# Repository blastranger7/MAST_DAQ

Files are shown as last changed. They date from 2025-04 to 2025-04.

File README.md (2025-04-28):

# MAST_DAQ

## A data aquisition system for the McMaster Aerospace Team
Intended to gather altitude, accelleration, and GPS data and save it to a SD card as a csv file.

### Hardware
> ESP32

> GT-U7  GPS Module

> MPU6050 Accelerometer

> Micro SD Card adapter

### Use
Turning the system on will immediately create a new csv file on the SD card and start writing accelerometer and GPS data to it.

If the system in turned on and GPS data is all 0s then the likely cause is bad sattelite reception and you need to move outside.

### Notes

.cddx file is used to design the circuit diagram at https://www.circuit-diagram.org/editor/

The SD Card in this system needs to be formatted to FAT32. Most SD cards do not come this way and it is likely third party software is needed if the SD card is over 32GB. Free software can be found to do this, although I've found that **DiskGenius** (https://www.diskgenius.com) works the best (also free).

Use an ESP32 and not an Arduino as an Arduino doesn't have enough SRAM to handle the 3 communication protocols needed.

Hold down the boot button on the ESP32 for a second or two while connecing when uploading code

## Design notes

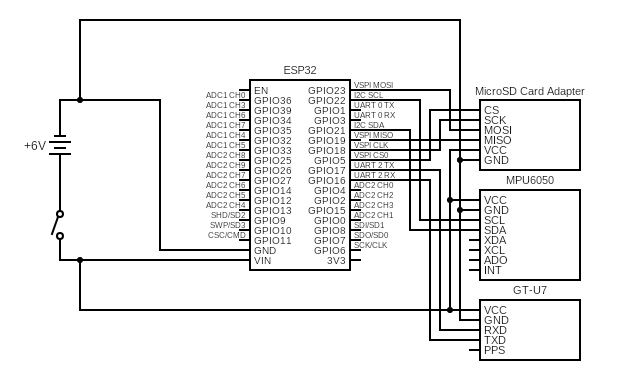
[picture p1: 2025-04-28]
DAQ_ESP32_CD.png

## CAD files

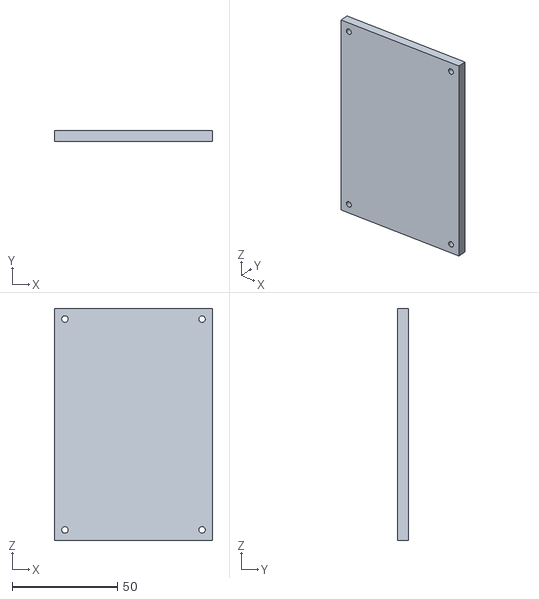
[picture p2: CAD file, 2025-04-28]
Housing/DAQ_HousingCover_V1.stl
75.0 x 5.00 x 110.0

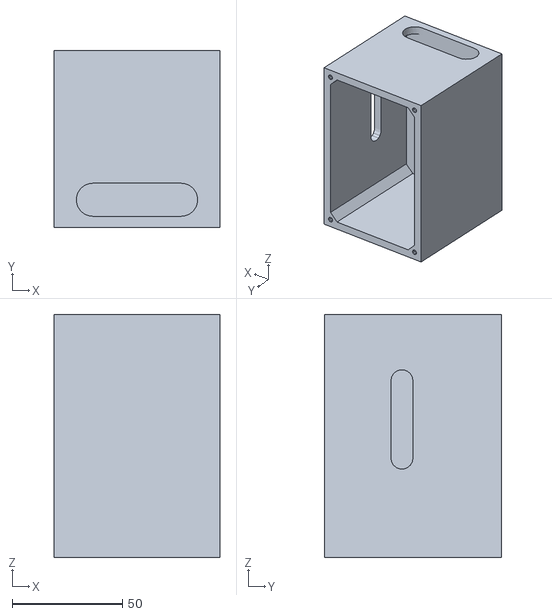
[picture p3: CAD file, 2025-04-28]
Housing/DAQ_Housing_V1.stl
75.0 x 80.0 x 110.0

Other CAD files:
Housing/DAQ_HousingCover_V1.ipt
Housing/DAQ_Housing_V1.ipt

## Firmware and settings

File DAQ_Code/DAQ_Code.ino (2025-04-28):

//libraries
#include <Wire.h>
#include <SPI.h>
#include <SD.h>
#include <SoftwareSerial.h>
#include <TinyGPS.h>
#include <FS.h>
//#include <Servo.h>

//SD card module setup. Change chipSelect to the digital pin you are using
File myFile;
/*Sd2Card card;
SdVolume volume;
SdFile root;*/
int chipSelect = 5;
 
//these are for file name creation change baseName to whatever name you want.
//baseName cannot be longer than 6 charactars
#define baseName "/flight"
const uint8_t baseNameSize = sizeof(baseName) - 1;
char fileName[] = baseName "00.csv";

//how many second the program has been run for
int secondsRun = 0;

//values for voltage divider
//adjust the inputAdjustment value if your voltage is not correct
//float inputVoltage = 0.0;
//const float inputAdjustment = 0.75;
//const float voltageDivider = 2.0;

//gps setup
TinyGPS gps;
SoftwareSerial ss(16, 17);//software serial pins RX,TX

//gps variables
//how many hours ahead or behind utc you are. Needs to be configured to display the correct time
float timezone = 0;
float flat, flon,speed,altitude;
unsigned  long age, date, timee;
int year;
byte month, day, hour, minute, second, hundredths,satellites;

// MPU VALUES
#define SEALEVELPRESSURE_HPA (1018.8)
const int MPU = 0x68; // MPU6050 I2C address
float AccX, AccY, AccZ;
float GyroX, GyroY, GyroZ;
float accAngleX, accAngleY, gyroAngleX, gyroAngleY, gyroAngleZ;
float roll, pitch, yaw;
float AccErrorX, AccErrorY, GyroErrorX, GyroErrorY, GyroErrorZ;
float elapsedTime, currentTime, previousTime;

void setup() {
  Serial.begin(9600);
  ss.begin(9600);
  Wire.begin();                      // Initialize comunication
  Wire.beginTransmission(MPU);       // Start communication with MPU6050 // MPU=0x68
  Wire.write(0x6B);                  // Talk to the register 6B
  Wire.write(0x00);                  // Make reset - place a 0 into the 6B register
  Wire.endTransmission(true);        //end the transmission
  Wire.beginTransmission(MPU);
  Wire.write(0x1C);                  //Talk to the ACCEL_CONFIG register (1C hex)
  Wire.write(0x10);                  //Set the register bits as 00010000 (+/- 8g full scale range)
  Wire.endTransmission(true);
  
  Serial.print("Simple TinyGPS library v. "); Serial.println(TinyGPS::library_version());
  Serial.println();
  //SD card initialization
  /*Serial.println(SS);
  Serial.println(MOSI);
  Serial.println(MISO);
  Serial.println(SCK);*/
  //pinMode(5, OUTPUT);
  //digitalWrite(5, HIGH);
  SPI.begin(18,19,23,chipSelect);
  if (!SD.begin(chipSelect)) {
    Serial.println("initialization failed!");
    return;
  }
  
  uint8_t cardType = SD.cardType();

  if(cardType == CARD_NONE){
    Serial.println("No SD card attached");
    return;
  }

  /*Serial.print("SD Card Type: ");
  if(cardType == CARD_MMC){
    Serial.println("MMC");
  } else if(cardType == CARD_SD){
    Serial.println("SDSC");
  } else if(cardType == CARD_SDHC){
    Serial.println("SDHC");
  } else {
    Serial.println("UNKNOWN");
  }

  uint64_t cardSize = SD.cardSize() / (1024 * 1024);
  Serial.printf("SD Card Size: %lluMB\n", cardSize);*/
  fileSetup();
}


void loop() {
  {
  bool newData = false;
  unsigned long chars;
  unsigned short sentences, failed;
  for (unsigned long start = millis(); millis() - start < 1000;)
  {
    while (ss.available())
    {
      char c = ss.read();
      //Serial.write(c); // uncomment this line if you want to see the GPS data flowing
      if (gps.encode(c)) // Did a new valid sentence come in?
        gpsValueUpdate();
     }
  }
  //Serial.println("Recieved GPS Data");
  if(satellites > 3){
    //secondsRun++;
    //batteryVoltage(); //call for battery voltage reading
      //update the file
  }
  
  gps.stats(&chars, &sentences, &failed);//check valid data is being recieved from gps
  if (chars == 0)
    Serial.println("** No characters received from GPS: check wiring **");
  }
  updateFile();

  Serial.print(AccX);
  Serial.print("/");
  Serial.print(AccY);
  Serial.print("/");
  Serial.println(AccZ);
  //delay(500);
}


void updateFile(){
  //Serial.println("entered");
  getAcc();
  File myFile = SD.open(fileName, FILE_APPEND);
  if (myFile) {
    //Serial.println("updating");
     //print all the data to the spreadsheet seperated by commas
     //myFile.print(secondsRun);
     //myFile.print(", ");
     myFile.print(hour+timezone);
     myFile.print(":");
     myFile.print(minute);
     myFile.print(":");
     myFile.print(second);
     myFile.print(", ");
     myFile.print(AccX);
     myFile.print(", ");
     myFile.print(AccY);
     myFile.print(", ");
     myFile.print(AccZ);
     myFile.print(", ");
     //myFile.print(inputVoltage);
     //myFile.print(",");
     myFile.print(altitude);
     myFile.print(",");
     myFile.print(speed);
     myFile.print(",");
     myFile.print(satellites);
     myFile.print(",");
     myFile.print(flat == TinyGPS::GPS_INVALID_F_ANGLE ? 0.0 : flat, 6);
     myFile.print(",");
     myFile.println(flon == TinyGPS::GPS_INVALID_F_ANGLE ? 0.0 : flon, 6);
     //Serial.println("updated");
  }else{
    Serial.println("Write failure");
  }
  myFile.close();
}


void fileSetup(){
  //name creation
  while (SD.exists(fileName)) {
    if (fileName[baseNameSize + 1] != '9') {
      fileName[baseNameSize + 1]++;
    } else if (fileName[baseNameSize] != '9') {
      fileName[baseNameSize + 1] = '0';
      fileName[baseNameSize]++;
    } else {
      Serial.println(F("Can't create file name"));
      return;
    }
  }
  File myFile = SD.open(fileName, FILE_APPEND);
  myFile.println("");
  myFile.println("Time,AccX,AccY,AccZ,Altitude,Speed,Gps Sats,Lat,Long");//column labeling
  myFile.close();
  Serial.println("File Created");
}

/*void batteryVoltage(){
  int analog_value = analogRead(A3);//get analog voltage from voltage divider
  inputVoltage = (analog_value * 5.0) / 1024.0; //calculate voltage from analog value
  if (analog_value < 460){
    inputVoltage = 0.0;
  }

  else{
    inputVoltage *= voltageDivider; //apply voltage divider
    inputVoltage += inputAdjustment;  //apply voltage inputAdjustment
  }
}
*/
void gpsValueUpdate(){
  gps.f_get_position(&flat, &flon);
  satellites = gps.satellites() == TinyGPS::GPS_INVALID_SATELLITES ? 0 : gps.satellites();//get number of GPS satellites
  speed = gps.f_speed_mps();  //get speed. I am using mp/s but this can be changed to f_speed_mph or f_speed_kmh for difrent units
  altitude = gps.altitude()/100; //Get altitude from GPD
  gps.get_datetime(&date, &timee, &age);
  gps.crack_datetime(&year, &month, &day, &hour, &minute, &second, &hundredths, &age); //update time from GPS
}

void getAcc(){
  Wire.beginTransmission(MPU);
  Wire.write(0x3B); // Start with register 0x3B (ACCEL_XOUT_H)
  Wire.endTransmission(false);
  Wire.requestFrom(MPU, 6, true); // Read 6 registers total, each axis value is stored in 2 registers
  //For a range of +-2g, we need to divide the raw values by 16384, according to the datasheet
  AccX = (Wire.read() << 8 | Wire.read()) / 4096.0; // X-axis value
  AccY = (Wire.read() << 8 | Wire.read()) / 4096.0; // Y-axis value
  AccZ = (Wire.read() << 8 | Wire.read()) / 4096.0; // Z-axis value 
}

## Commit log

2024-03-04 Circuit Diagram and Pin adjustments. Serial still doesn't work
2025-04-19 New Circuit Diagram and edits to DAQ_Code
2025-04-28 Updated README, Circuit, Housing, Code.
    [DAQ_HousingCover_V1.ipt, DAQ_HousingCover_V1.stl, DAQ_Housing_V1.ipt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]
